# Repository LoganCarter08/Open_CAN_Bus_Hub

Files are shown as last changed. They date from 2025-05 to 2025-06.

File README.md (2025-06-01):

# Open CAN Bus Hub

An open source alternative to a CAN bus hub primarily used in aftermarket automotive industry.

## Overview

This project is intended to reduce the cost of a simple part needed for many project cars. If you are building a car and need to add aftermarket equipment via CAN bus you will likely need a hub of some sort to distribute the network to each of your devices.

The existing products like [AEM](https://www.aemelectronics.com/products/ev_conversions/wiring_shop/wiring_harnesses/parts/30-2225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), [Haltech](https://www.haltech.com/product/ht-159000-elite-can-hub-4-port-dtm-4/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), and [CANChecked](https://trailbrake.com/canchecked-cbd08-bus-hub/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) are very expensive, are limited to a few devices after connecting the ECU, and often require external resistor termination. This project addresses these issues.

This project will walk you through building your own CAN bus hub to meet your needs.

## Design Notes

- The industry standard for automotive CAN bus has become DTM plugs, so utilizing these was a priority
- Minimizing the number of wires to keep complexity and risk of issues was the primary priority. Later versions may attempt to eliminate the need for any wires regardless of number of rows.
- Handling high(ish) current was something we regarded as important as users may be powering many devices from one hub. See the important section for more info on power capabilities.

## IMPORTANT

- Do not exceed 10 amps total on the hub unless you custom order heavier than 2oz copper on the board. This means all of your plugs combined should not exceed 10 amps. It would be ideal to put a fuse prior to the hub to ensure this is not exceeded. Read the PCB readme for more information on amperage.
- Do not exceed 7 amps total on each of the plugs unless you custom order heavier than 2oz copper on the board. The DTM pins are only capable of 7 amps and so is the PCB. Read the PCB readme for more information on amperage.
- This design does not support the DTM waterproof gasket that comes with standard DTM plugs. This is partly due to the high cost of the gasket ($4 each) and partly due to the added complexity for 3D printing. Due to this is it not recommended to use this design in an area that will see direct contact with water or particulates that can cause electrical problems.

## Tools Needed

Note: All Amazon links below are just to serve as an example of what you are looking for. These can be substituted with any equivalent tool.

| **Tool** | **Details** | **Link** |
| --- | --- | --- |
| Soldering Iron | Any will do, but a pointed tip is helpful | https://amzn.to/42WFt6c |
| 3D Printer | Read the FAQ if you do not have one. | |
| Allen Keys | They'll often send some with bolts. | https://amzn.to/4j0mix5 |
| Needle Nose Pliars | These are not required, but make assembly easier. | https://amzn.to/3GLlzma |
| Wire Strippers | Only needed if doing more than one row. | https://amzn.to/4kl7wSS |

## Parts Needed

Note: All Amazon links below are just to serve as an example of what you are looking for. These can be substituted with any equivalent part.

| **Part** | **Details** | **Link** |
| --- | --- | --- |
| Solder | Pretty much any basic solder for electronics should work well. | https://amzn.to/4mdSlfK |
| Filament | I recommend ASA | https://amzn.to/44zXtVi |
| DTM Pins | PN: 0460-202-20141 | https://www.te.com/en/product-0460-202-20141.html |
| M2 Bolts | M2x4mm socket cap | https://amzn.to/3GLZ6FB |
| M3 Bolts | M3x12mm flat cap | https://amzn.to/3GRSxkQ |
| M2 Threaded Inserts | M2x3.2mmx4mm | https://amzn.to/4m9bsb3 |
| M3 Threaded Inserts | M3x5mmx4mm | https://amzn.to/3EYypgh |
| 120ohm Resistor | 1/4 watt | https://amzn.to/42SdeFQ |
| PCBs | View PCB readme for more info on ordering | https://www.pcbway.com/project/shareproject/Open_CAN_Bus_Hub_V1_0_372ae918.html |
| Wire | Only needed if doing more than 1 row. Size according to your power needs. | |

## Build/Assemble

1. Follow the [instructions](https://github.com/LoganCarter08/Open_CAN_Bus_Hub/tree/main/Model) in the Model readme for how to make and assemble the case for the hub that houses everything.
2. Follow the [instructions](https://github.com/LoganCarter08/Open_CAN_Bus_Hub/tree/main/PCB) in the PCB readme for how to order and assemble the PCBs.
3. If you are adding a termination resistor, solder it into the PCB that needs it. It is recommended to add it to the last PCB in the hub, furthest from the ECU. Make sure to snip the excess leads flush with the PCB to ensure good fitment into the printed piece and no chances of shorting.
4. Solder the pads between each PCB. This means each pad should be soldered to the corresponding pad on the adjacent PCBs. If you are having a hard time getting your solder to bridge the gap it may be helpful to put a piece of wire without insulation between the boards or even a single strand from a multi strand wire.
   connected PCBs
5. Repeat step 11 for every row in your box.
6. If you have more than 1 row you will need to connect each row with wires here. Make sure to keep the wires as short as possible as any excess will make bolting the bottom half on more difficult. If you need your box to handle higher amperages it is recommended to solder your power and ground wires to the through holes next to the corresponding pads. These will likely provide a better solder point for thicker wires and be more reliable.
7. Using the M3 bolts bolt the bottom half of the hub to the top half.
8. Install into the car and plug in all of your devices!

## FAQ

**Q. How much does it cost to build?**

A. This will depend on how many plugs you need, but a quick breakdown might look like the following. All prices are in USD and estimates based on my purchases. This assumes you have all tools.

| **Part** | **Cost Estimate Each** | **Quantity** |
| --- | --- | --- |
| Pins | $0.15 - $0.24 | 4 per plug |
| PCB | $0.54 - $5.4 | 1 per plug |
| Filament | $0.30 - $0.50 | 1 per plug |
| M2 Bolts | $0.08 | min of 2 per plug |
| M3 Bolts | $0.17 | min of 4 |
| M2 Threaded Inserts | $0.06 | min of 2 per plug |
| M3 Threaded Inserts | $0.09 | min of 4 |

**Note:** The more PCB you order the cheaper they are. Example: A 10 plug hub should cost around $40 if you only bought 10 PCBs. A 20 plug hub should cost around $50 if you only bought 20 PCBs.

**Q. What pin orientation is used?**

A. The intended orientation is what Link ECU uses, but should also work with Haltech and others. You may notice that in both versions pins 1 and 2 are power and ground and pins 3 and 4 are CAN low and CAN high. Power and ground pins can be interchanged and so can the CAN low and high as long as every device that is plugged into this hub follows this standard. If this isn't clear just think of the markings on the PCB as CAN 1 and CAN 2. They don't actually care if they are high or low. They are just marked to make it easier for assembly. Same with power and ground. These are sized the same internally, so you could use the power pin as the ground and vice versa if you need to for your application.

Link's orientation:

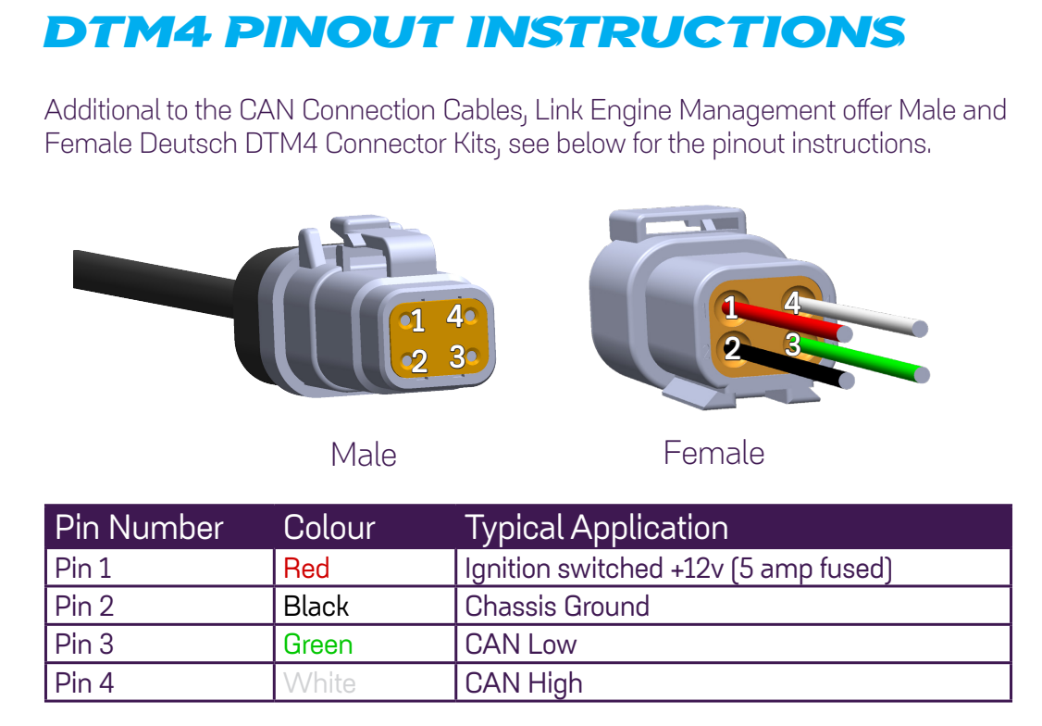
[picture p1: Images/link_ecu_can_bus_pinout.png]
Link ECU CAN pinout


Haltech's orientation (wire side):

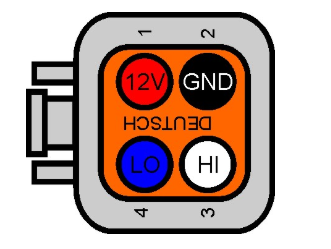
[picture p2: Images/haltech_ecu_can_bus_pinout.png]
Haltech ECU CAN pinout


**Q. I only need x number of PCBs and it is more expensive to order small amounts.**

A. If you are in the US feel free to contact me. I might have some available and if not I may do a bulk order, depending on interest, to lower the cost per individuals. I can do the same with the pins and resistors too. Shipping outside of the US will likely be more expensive than you ordering them from a manufacturer directly.

**Q. Can I sell these?**

A. I put this project under an MIT license. You are free to sell them if you would like. I just ask that you add a reference back to this project so it can help people who are looking for a DIY solution.

**Q. What if I don't have a 3D printer?**

A. Depending on your budget or needs you can either find a 3D printing service to print it for you, look for local hobbiest with printers, check your local library for printer usage, or you can contact me if you are in the US.

**Q. Do I need to know CAD?**

A. CAD skills are really helpful here. The design is partially parametric, but it is missing brackets for mounting. These will likely need to change per user, so they are not included in the model. I will likely upload some STEP files with some sizes with random mount designs just to give people options. Visit the readme in the Model folder for more information.

**Q. Do I need to know PCB design?**

A. Not unless you need to make changes to the design or want to contribute to the project.

## Disclaimers

- All Amazon links are affiliate links.
- The PCBWay page for the PCB does give me some money for each order placed.

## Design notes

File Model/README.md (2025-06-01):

# Open CAN Bus Hub CAD Model

The following is intended to help with usage and modification of the parametric CAN hub 3D model.

## What Do I Need?

You will need Fusion 360 and some mild CAD skills. The hard work of the model should be done for you, you just need to add mounting to fit your needs. If you are new to CAD then read the FAQ below to learn more.

## Design Instructions:

1. Make sure Fusion 360 is installed on your computer.
2. Download the can_hub_parametric_model.f3d from this folder onto your computer.
3. Open Fusion 360
4. Click File -> Open
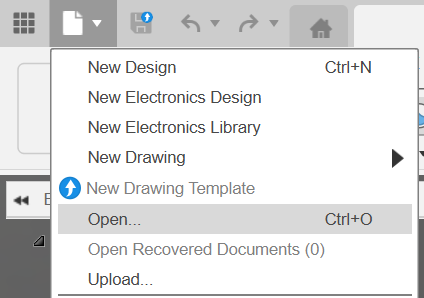
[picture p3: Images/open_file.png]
Open File
   
5. Click the Open From My Computer button
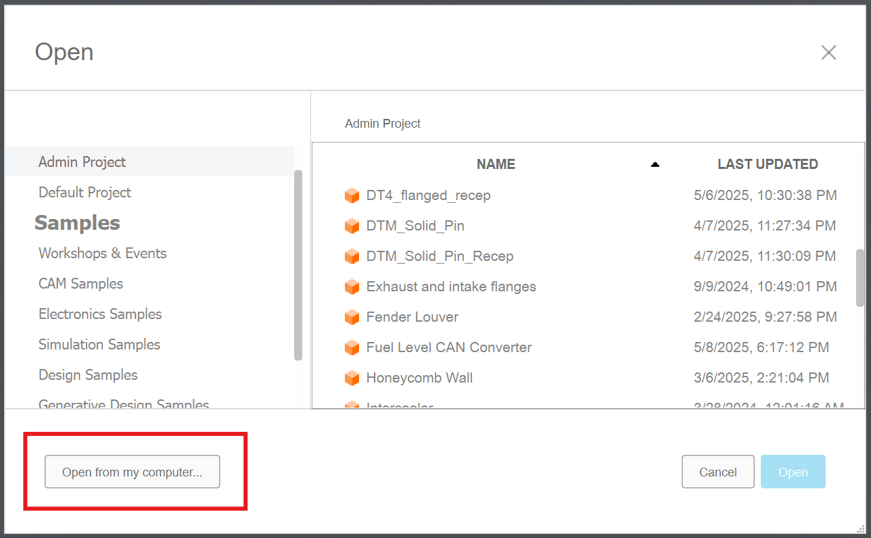
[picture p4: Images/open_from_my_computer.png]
Open From my computer
   
6. Navigate to the can_hub_parametric_model.f3d file and select it
7. Under MODIFY press the Change Parameters button
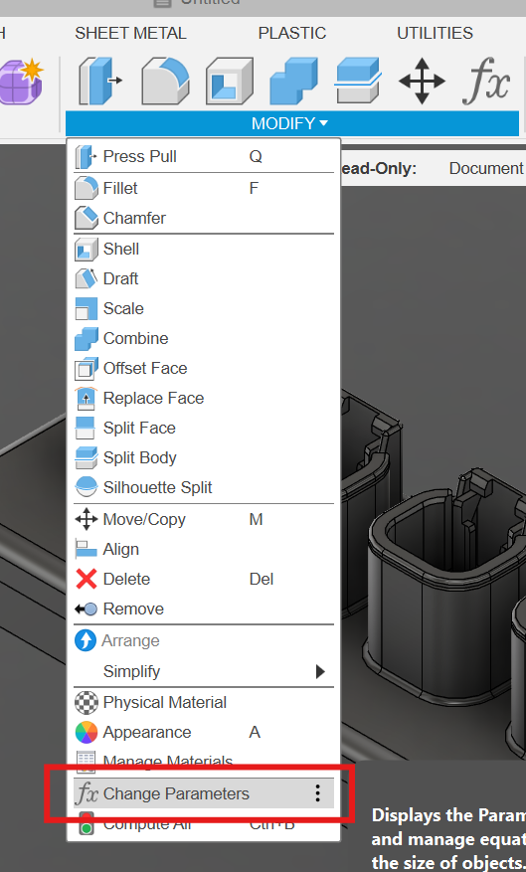
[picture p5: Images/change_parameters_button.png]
Change params button
   
8. Under this menu you will find 3 parameters that you may want to change. They are described below. Once you change any of these Fusion will redraw the model. This may take some time depending on the speed of your machine.

   **row:** The number of rows of plugs you want.

   **col:** The number of columns of plugs you want. Note that PCBs are designed so that they are soldered in the column direction. Meaning you should plan to have more columns than rows.

   **plugScale:** Scale of the plug. If your printer doesn't print internals accurately this is a way to fine tune that without throwing off other dimensions.

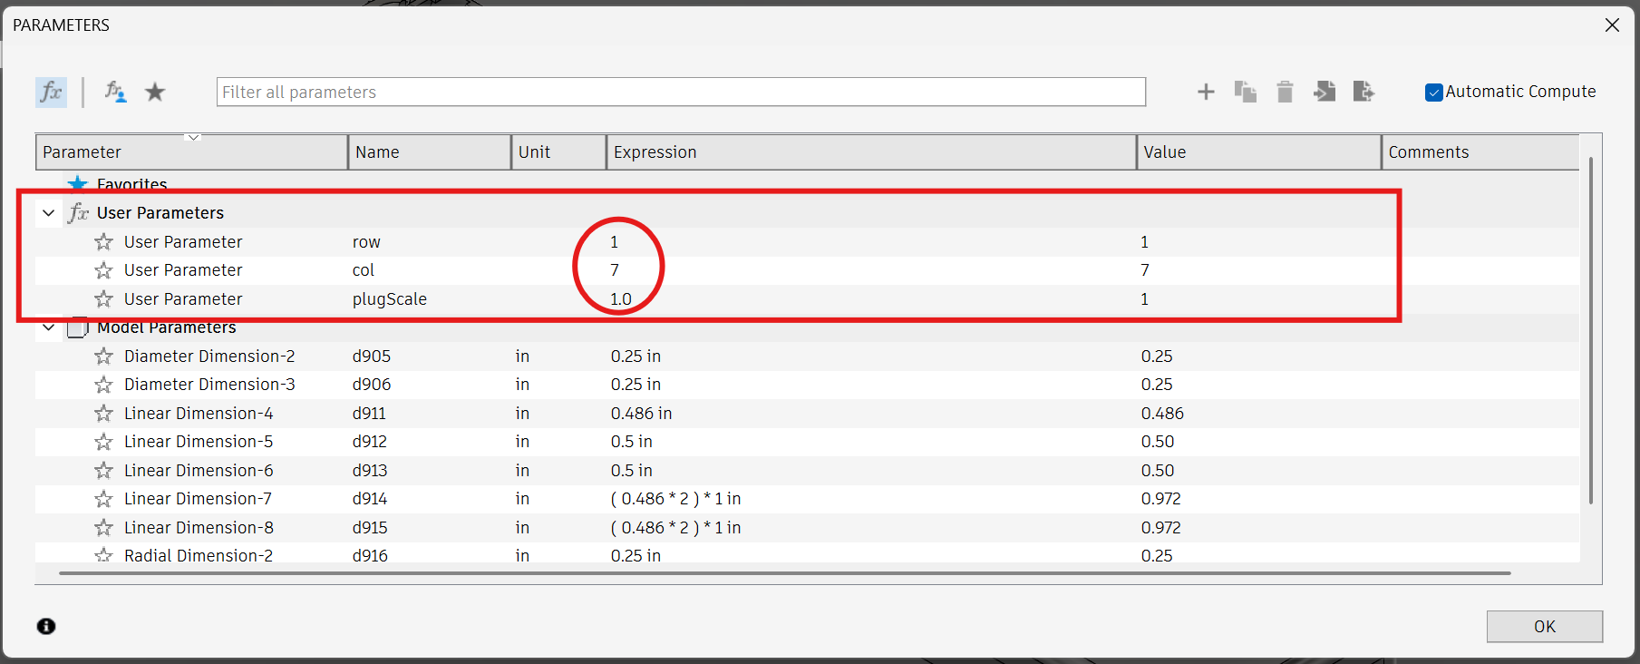
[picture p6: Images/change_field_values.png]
Change Params


**The following two steps are optional, but highly recommended.**

9. Create a mount. There are no mounts in the parametric model and you will likely need a way to mount these in your car. It is up to you to add a mount to the model from here
10. Add extra bolts between top and bottom. If you look at the model there are 4 bolts holding it together. If you have a very large box you will likely experience some gaps between the two pieces without bolts in the middle. These are left out because it's too ambiguous to parametrically decide when and where to add the extra bolts.
11. To save the models for printing find them in the Navigation -> Bodies folder, right click, hit Save as Mesh, press OK on the next menu, select where to save the file to and hit Save. You will need to do this for both the top and bottom pieces.
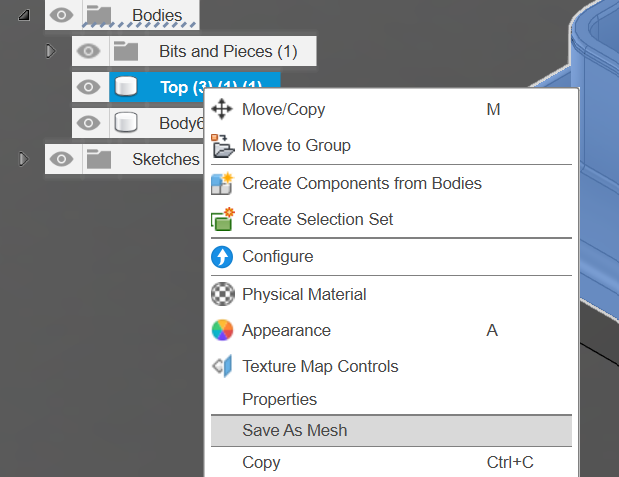
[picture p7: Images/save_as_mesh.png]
Save as mesh
    

## Assembly Instructions:

1. Melt the M3 threaded inserts into the top piece. These will be in each of the four corners plus any you may have added in the design process.
2. Melt a minimum of two inserts into the top piece where the PCB will attach. If you only do two make sure they are diagonal from each other.
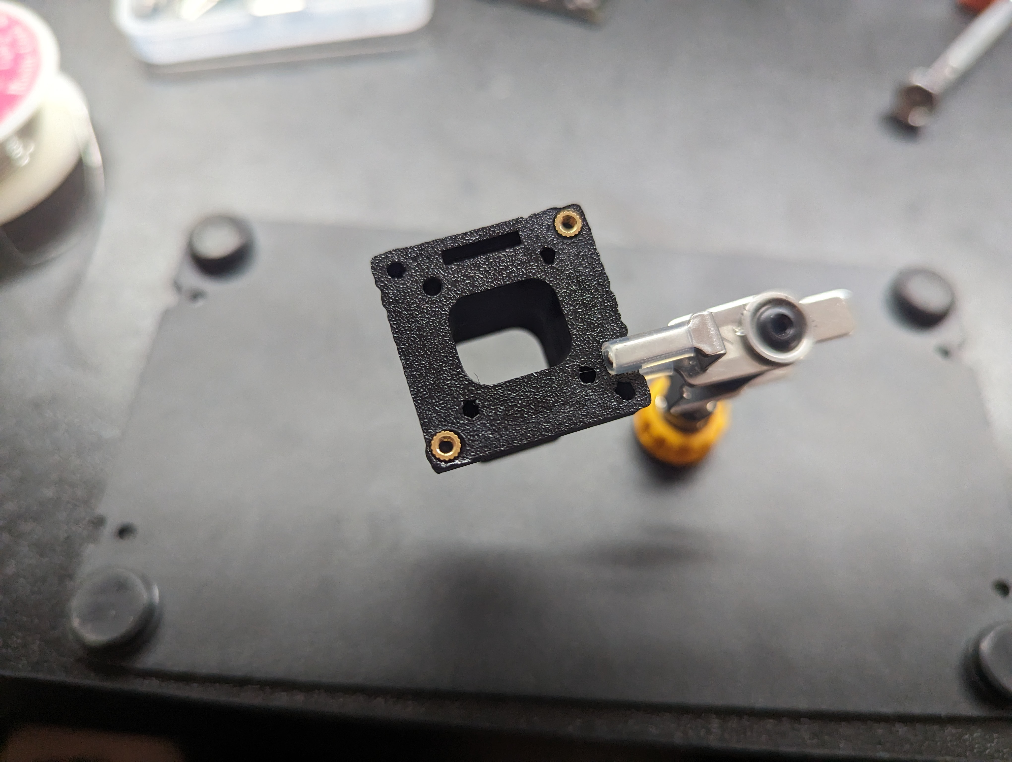
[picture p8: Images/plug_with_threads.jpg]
plug with inserts
   
3. Repeat steps 1 and 2 for every plug in your hub.

## Tips:

1. I would suggest opening the Bodies -> Bits and Pieces folder and printing the single top piece to test with your plugs before printing the full model. Some printers aren't as dimensionally accurate as others. If the recepticle is too small or too large try adjusting the plugScale parameter until it fits properly.

## Notes:

1. The bottom body is not called bottom. It will likely be called Body648 in your version. This may be corrected in the future.
2. The top body will have some numbers after Top in parenthesis. This is from the pattern tool. I had some issues with renaming it in the past so it has been stuck with this name. This may be corrected in the future.

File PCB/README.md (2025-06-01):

# Open CAN Bus Hub PCB

The following is intended to help with ordering and assembly of the PCB.

## What Do I Need?

If you plan to modify the PCB or order it from somewhere other than PCBWay you will need KiCad 9.0 or newer.

## Ordering:

If you are in the US and looking to place a small order, feel free to contact me as I might have some that I can ship out. Small batch orders of PCBs are generally much more expensive per board than bulk orders.

### PCBWay:

The design has been shared on PCBWay and can be ordered [here](https://www.pcbway.com/project/shareproject/Open_CAN_Bus_Hub_V1_0_372ae918.html). My suggestion would be to set the edge connector field to "No" versus the default "Yes". If you do not, it is likely PCBWay will contact you to ask you some details about the edge connection. This is not a normal edge connection and can be handled as a solder pad during manufacturing. From there the rest can be default or any other option you may want.
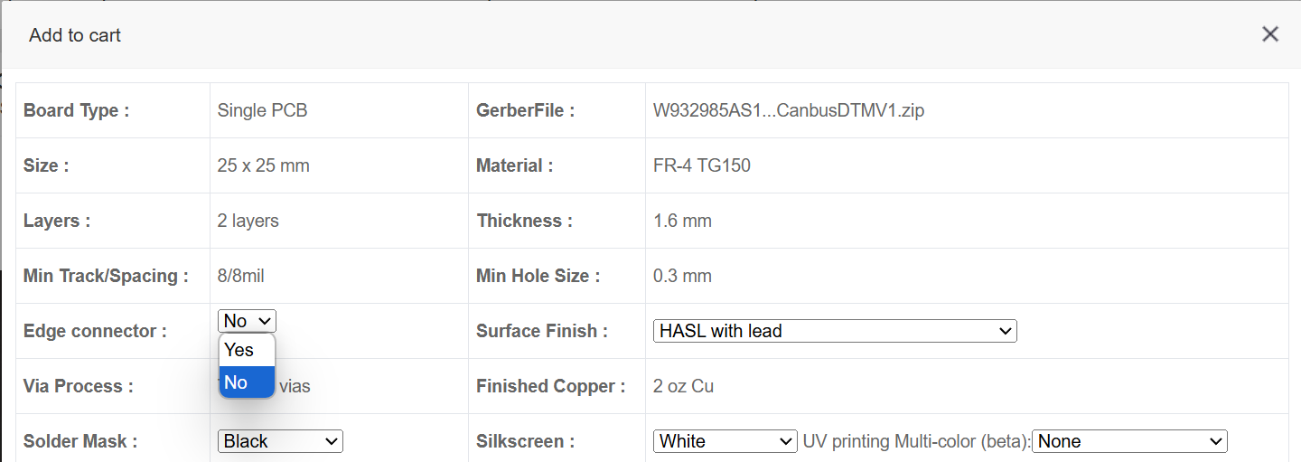
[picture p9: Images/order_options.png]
pcbway no edge connection


### Other Manufacturers:

1. Open KiCad
2. Press File -> Open Project and select the DTM4CanbusPCB.kicad_pro file from this folder
3. Double click to open the DTM4CanbusPCB-Board.kicad_pcb file
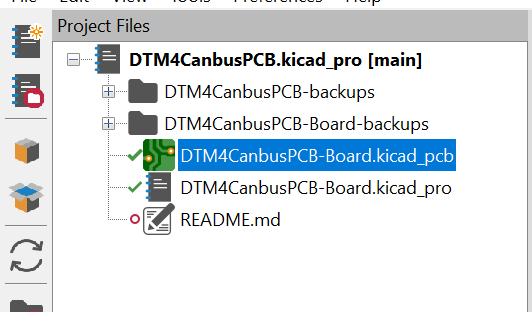
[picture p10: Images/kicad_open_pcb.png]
open pcb
   
4. Press File -> Fabrication Outputs->Gerbers (.gbr)...
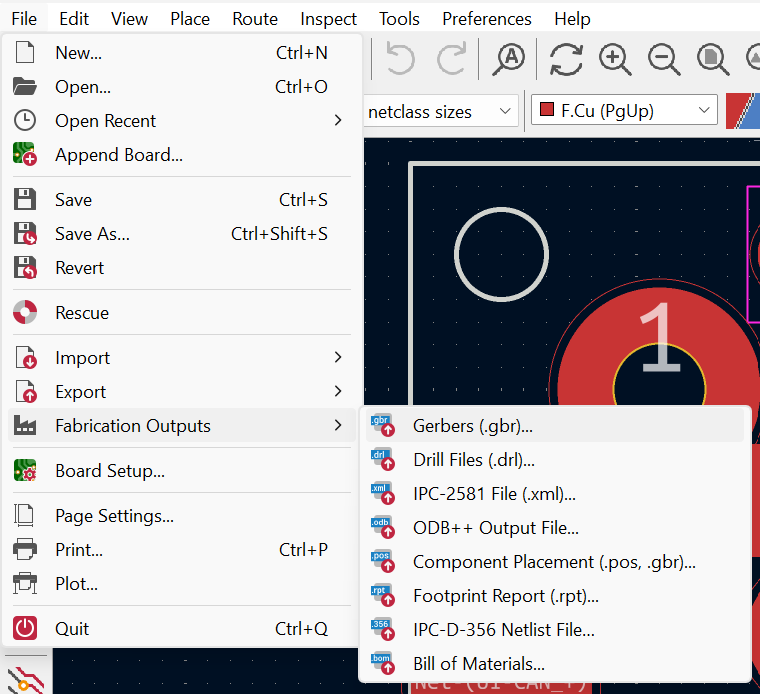
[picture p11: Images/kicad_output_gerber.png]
output gerber
   
5. Press Plot in the bottom right
6. Press Generate Drill Files... then press Generate on the next menu
7. Open the newly generated PCB\Gerber folder and zip all of these files up
8. Upload this zip to your favorite PCB manufacturer and place an order.

### Important Notes:

- When ordering it is recommended to use 2oz Cu or heavier for the finished copper. The more plugs in your hub the heavier you will want. Small hubs may be fine with 1oz, but please do research for your use case.

## Assembly Instructions:

1. Bolt each PCB to the top piece of the hub with the M2 bolts. Make sure the resistor is closest to the clip on the plug as shown below. The text on the PCB should be pointed away from the plug.
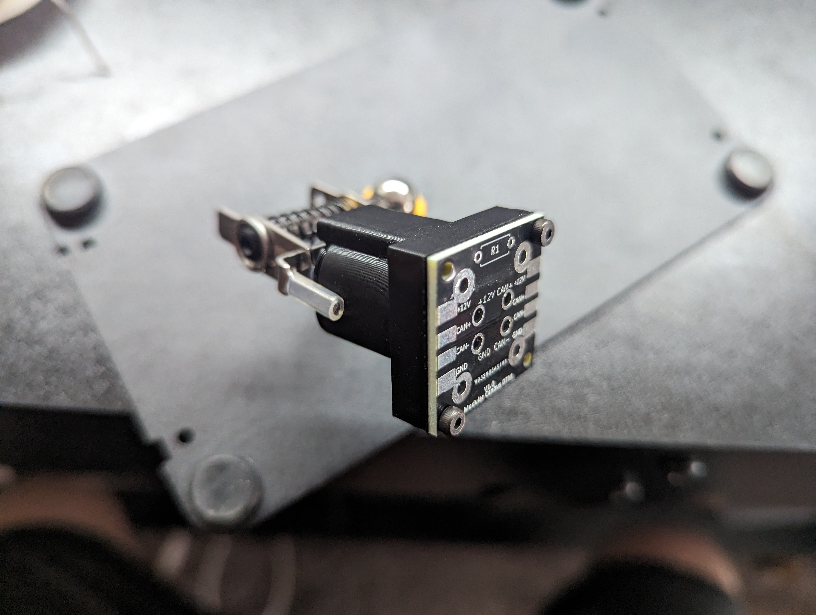
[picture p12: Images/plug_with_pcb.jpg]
plug with pcb
   
2. Using needle nose pliars insert the DTM pins into the holes on the PCB through the plug.
3. Take a male DTM plug, with the pins in it, and insert it into the female portion of the plug making sure that all of your pins go into the pins on the male plug. You can gently push on the back of your pins to feel for resistance to make sure they are properly aligned and inserted.
4. Solder the pins to the PCB. Make sure you do not heat the pins up too much and melt the housing of your male plug.
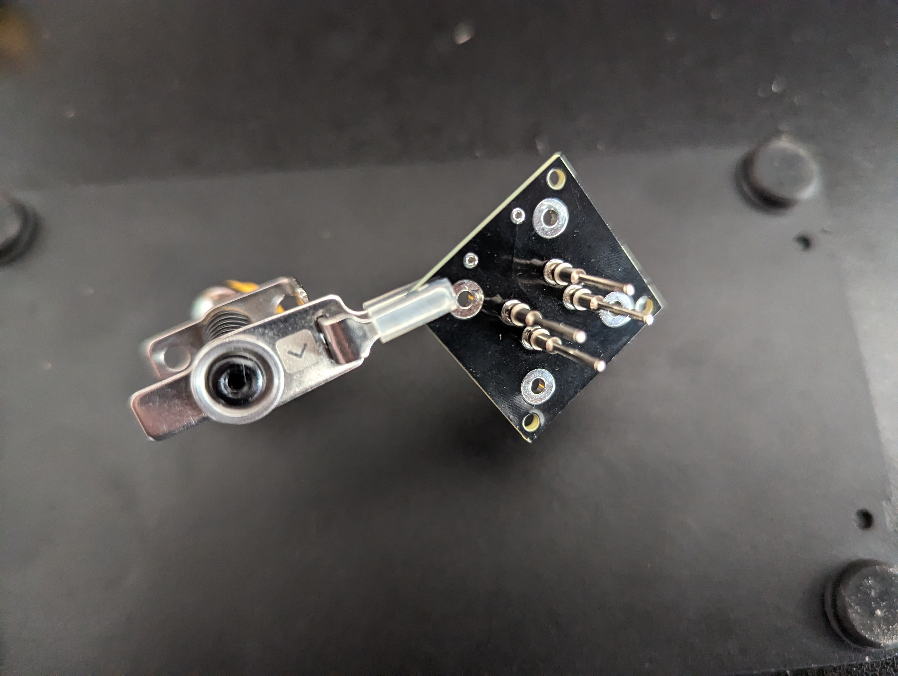
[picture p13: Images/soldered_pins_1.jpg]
soldered pins
   
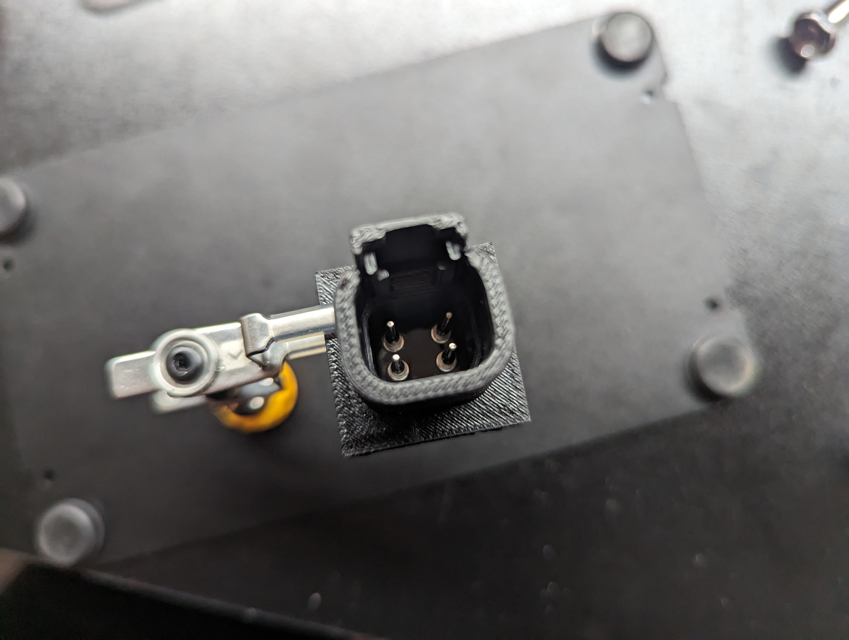
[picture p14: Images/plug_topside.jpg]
pins from above


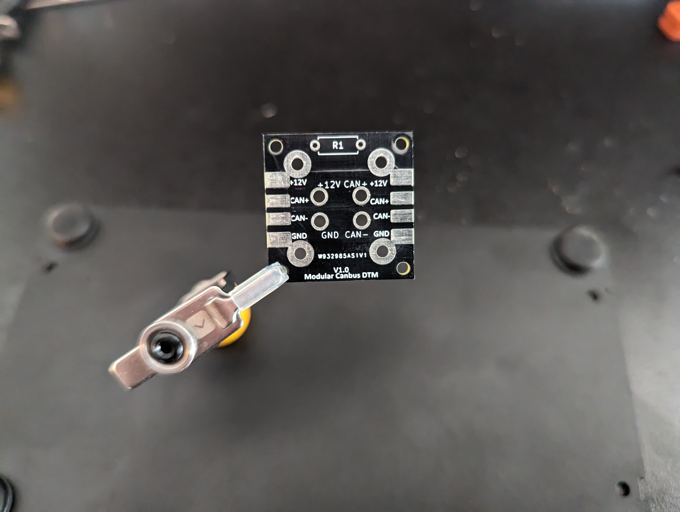
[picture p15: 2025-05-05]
Images/empty_pcb.jpg

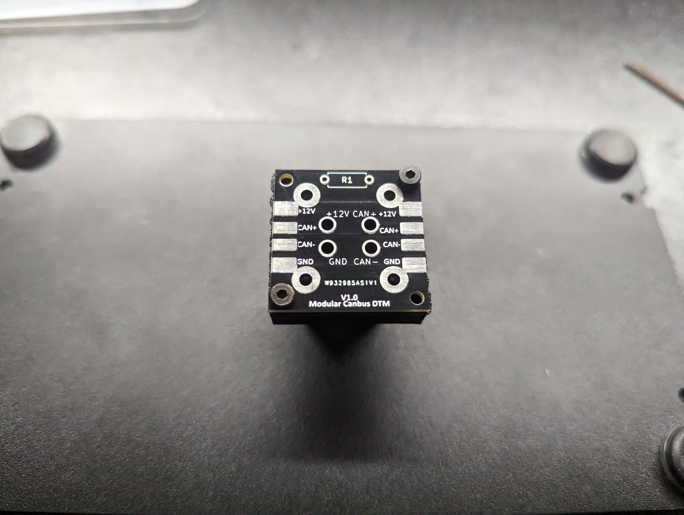
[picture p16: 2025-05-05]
Images/plug_with_empty_pcb.jpg

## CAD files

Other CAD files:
Model/can_hub_parametric_model.f3d

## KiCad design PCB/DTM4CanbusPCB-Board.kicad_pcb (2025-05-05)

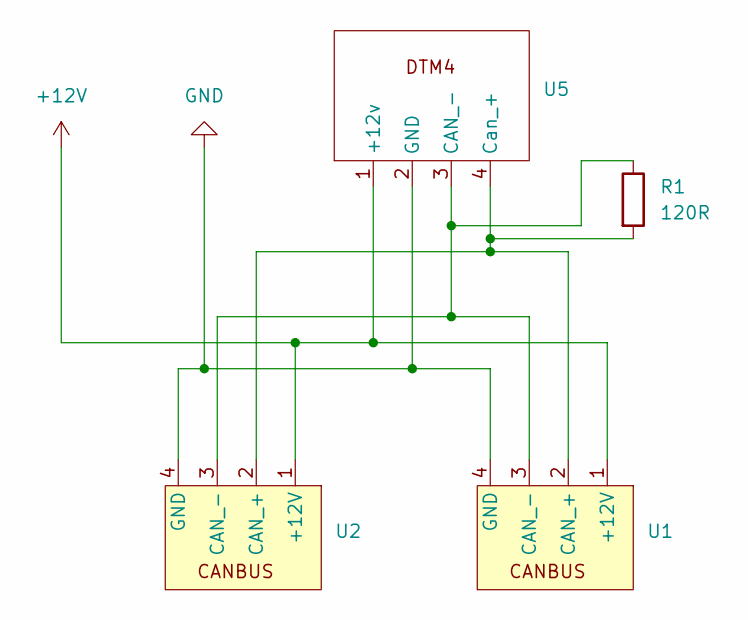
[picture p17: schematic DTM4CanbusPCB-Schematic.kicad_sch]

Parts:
R1: 120R; R_Axial_DIN0207_L6.3mm_D2.5mm_P7.62mm_Horizontal
U1: DTM4_CANBUS_Edge_Footprint
U2: DTM4_CANBUS_Edge_Footprint_Mirrored
U5: DTM4_CABUS_Pin_Footprint

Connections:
+12V: U1.1 (+12V), U2.1 (+12V), U5.1 (+12v)
GND: U1.4 (GND), U2.4 (GND), U5.2 (GND)
unnamed: R1.2, U1.2 (CAN_+), U2.2 (CAN_+), U5.4 (Can_+)
unnamed: R1.1, U1.3 (CAN_-), U2.3 (CAN_-), U5.3 (CAN_-)

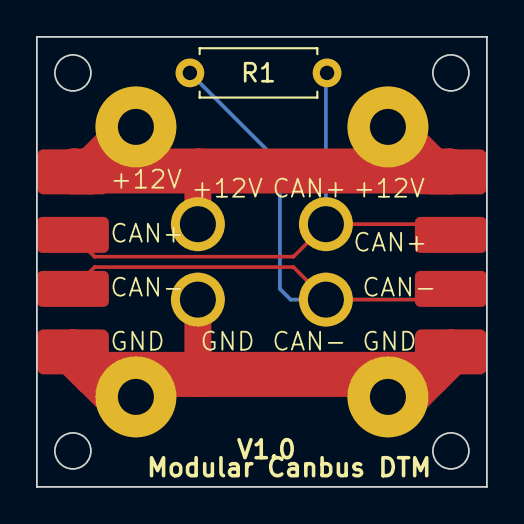
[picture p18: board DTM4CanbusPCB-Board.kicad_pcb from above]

Board: 2 copper layers, 25.0 x 25.0 mm, 4 parts (0 on the bottom side), 4 nets.

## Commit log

2025-05-05 adding initial pcb design
    [DTM4CanbusPCB-Board.kicad_pcb, DTM4CanbusPCB-Schematic.kicad_sch]
2025-05-05 adding initial parametric fusion model
    [can_hub_parametric_model.f3d]
2025-05-06 uploading gitignore in case there are any future contributors
2025-05-13 adding some links to parts and tools before doing the assembly guide
2025-05-15 adding mirrored resistor location to support flipped and rotated PCB mounting
